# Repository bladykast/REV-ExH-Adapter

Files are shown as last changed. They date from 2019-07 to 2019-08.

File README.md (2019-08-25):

# ExH Type-C

This is the open-source repository for the [Expansion Hub Type-C Adapter Board](https://www.tindie.com/products/doubledip/expansion-hub-type-c-adapter/).

V3 is the most current branch (in development). The master branch is for V2 (currently sold). V1.1 is also available (nonfunctional but archived).

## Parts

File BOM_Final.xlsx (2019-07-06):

Quantity | Part Number | Manufacturer P/N | Description | Comments
1 | 2073-USB4085-GF-ACT-ND | USB4085-GF-A | USB TYPE C, 2.0, REC, TH , G/F,
1 | 380-1412-ND | SS-52100-001 | CONN RCPT USB2.0 TYPEA 4POS R/A
1 | UX20-MB-5P-ND | UX20-MB-5P | CONN PLUG USB2.0 MINI B VERT | Expensive
1 | 490-9652-1-ND | XRCHA24M000F0A01R0 | CRYSTAL 24.0000MHZ 8PF SMD | Any 24mhz crystal
1 | USB2422/MJ-ND | USB2422/MJ | IC HUB CTLR USB 2.0 24QFN
1 | NCP170ASN330T2GOSCT-ND | NCP170ASN330T2G | ULTRA-LOW IQ 150 MA CMOS
1 | RMCF0603JT1M00CT-ND | RMCF0603JT1M00 | RES 1M OHM 5% 1/10W 0603 | Generic
3 | RMCF0603FT56K0CT-ND | RMCF0603FT56K0 | RES 56K OHM 1% 1/10W 0603 | Generic
1 | A129701CT-ND | CRGCQ0603F12K | RES 12K OHM 1% 1/10W 0603 | Generic
3 | 1276-1045-1-ND | CL10A475KQ8NNNC | CAP CER 4.7UF 6.3V X5R 0603 | Generic
3 | 1276-1866-1-ND | CL10A105MP8NNNC | CAP CER 1UF 10V X5R 0603 | Generic
2 | 1292-1494-1-ND | 0603N180J500CT | CAP CER 18PF 50V C0G/NP0 0603 | Generic

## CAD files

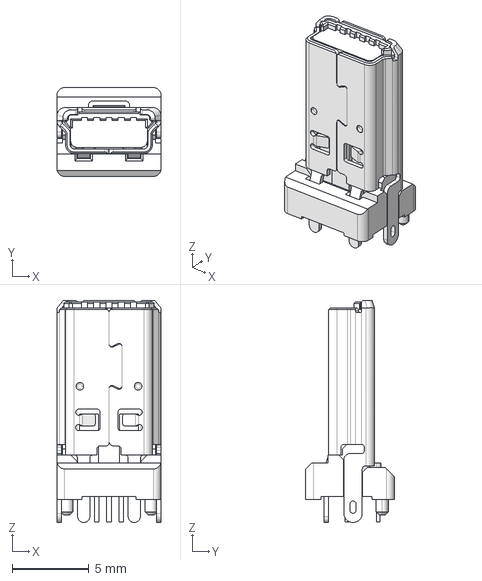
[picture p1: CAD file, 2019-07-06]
UX20-MB-5P.stp
6.80 x 5.80 x 14.5 mm

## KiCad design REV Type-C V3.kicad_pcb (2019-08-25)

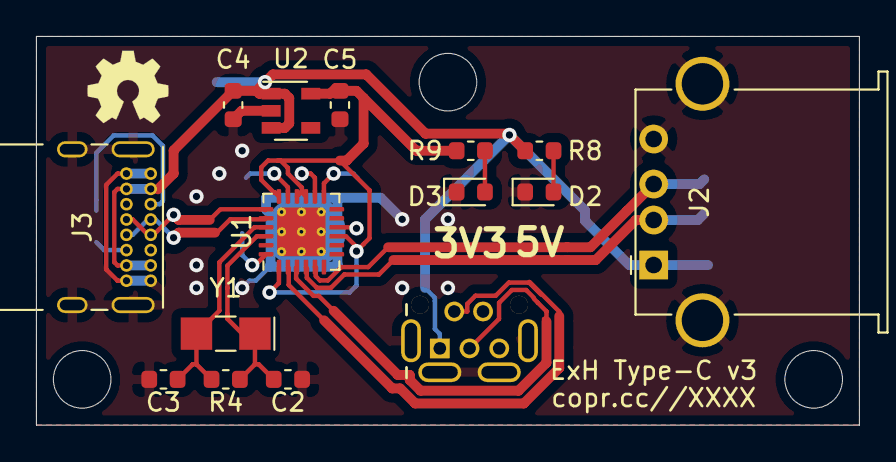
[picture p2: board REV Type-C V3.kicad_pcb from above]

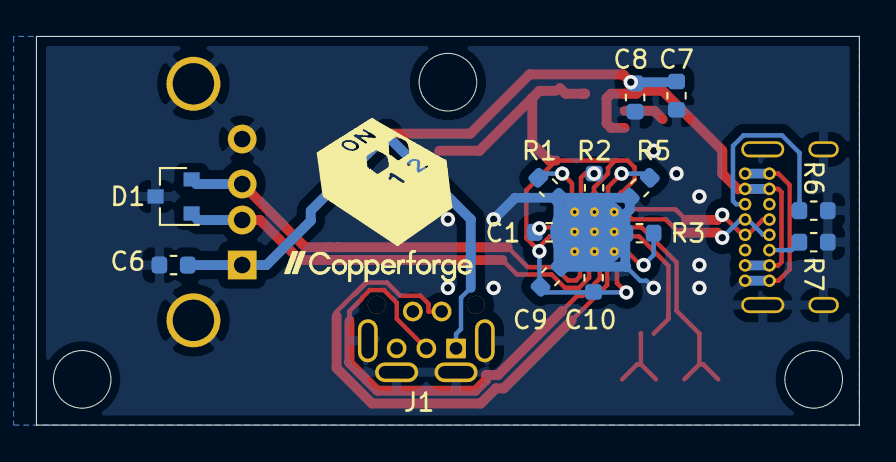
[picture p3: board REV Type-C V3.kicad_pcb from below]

Board: 2 copper layers, 45.7 x 21.6 mm, 30 parts (15 on the bottom side), 20 nets.

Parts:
C1: 1uf; C_0603_1608Metric
C2, C3: 18pF; C_0603_1608Metric
C4, C5, C9: 1uF; C_0603_1608Metric
C6, C7, C8: 4.7uF; C_0603_1608Metric
C10: 0.1uF; C_0603_1608Metric
D1: SP0502BAHT; SOT-23
D2, D3: LED; LED_0603_1608Metric
DD: DD_IRL_NoLegs
J1: USB_B_Mini; UX20-MB-5P
J2: USB_A; USB_A_Stewart_SS-52100-001_Horizontal
J3: USB_C_Receptacle_USB2.0; USB_C_Receptacle_GCT_USB4085
LOGO: CU_Logo_LG
R1, R2, R5: 56k; R_0603_1608Metric
R3: 12k; R_0603_1608Metric
R4: 1M; R_0603_1608Metric
R6, R7: 5.1k; R_0603_1608Metric
R8: 470; R_0603_1608Metric
R9: 220; R_0603_1608Metric
U1: USB2422; QFN-24-1EP_4x4mm_P0.5mm_EP2.7x2.7mm_ThermalVias
U2: MIC5504-3.3YM5; SOT-23-5
Y1: 24M; Crystal_SMD_G8-2Pin_3.2x1.5mm_HandSoldering

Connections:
+3V3: C5.1, C9.1, C10.2, R9.2, U1.1, U1.9, U1.15, U1.16, U1.18, U2.5
+5V: C4.1, C6.1, C7.1, C8.1, J1.1, J2.1, J3.A4, J3.A9, J3.B4, J3.B9, R8.2, U2.1, U2.3
/D1+: J1.3, U1.3
/D1-: J1.2, U1.2
/D2+: D1.2, J2.3, U1.5
/D2-: D1.1, J2.2, U1.4
/DIN+: J3.A6, J3.B6, U1.20
/DIN-: J3.A7, J3.B7, U1.19
/XTAL_I: C2.1, R4.2, U1.22, Y1.1
/XTAL_O: C3.1, R4.1, U1.21, Y1.2
GND: C1.1, C2.2, C3.2, C4.2, C5.2, C6.2, C7.2, C8.2, C9.2, C10.1, D1.3, D2.1, D3.1, J1.5, J1.6, J2.4, J2.5, J3.A1, J3.A12, J3.B1, J3.B12, J3.S1, R1.2, R2.2, R3.2, R5.1, R6.1, R7.1, U1.25, U2.2
unnamed: C1.2, U1.10
unnamed: D2.2, R8.1
unnamed: D3.2, R9.1
unnamed: J3.A5, R6.2
unnamed: J3.B5, R7.2
unnamed: R1.1, U1.13
unnamed: R2.1, U1.14
unnamed: R3.1, U1.24
unnamed: R5.2, U1.17

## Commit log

2019-07-06 Initial Files Commit
    [BOM_Final.xlsx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]
2019-08-19 Reorganize and prettify schematic
    [REV Type-C V2.sch]
2019-08-19 Update "REV" styling in document comments
    [REV Type-C V2.sch]
2019-08-24 Preliminary V3 files added
    [REV Type-C V3.kicad_pcb, REV Type-C V3.sch]
2019-08-25 V3 Preliminary Files
    [REV Type-C V3.kicad_pcb]
2019-08-25 Branch Cleanup
    [REV Type-C V2-B_Cu.gbr, REV Type-C V2-B_Mask.gbr, REV Type-C V2-B_Paste.gbr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]
2019-08-25 Fixed wrong Mini-B connector footprint
    [REV Type-C V3.kicad_pcb]
2019-08-25 Fix USB hub symbol in schematic
    [REV Type-C V3.sch]
